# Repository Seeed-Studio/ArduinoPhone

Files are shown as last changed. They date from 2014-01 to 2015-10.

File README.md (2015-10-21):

Arduino Phone
---------------------------------------------------------

Arduino Phone

Combining Arduino and other shield modules, we make a mobile phone named Arduino Phone. Meanwhile, we printed a shell for it with the 3D printer. Although it’s not such fine as you think, even a little bit clunky, it’s still very cool. That is the point this is a cell phone made by ourselves.

<br>
### Usage:

This is a Sketchbook of Arduino.([How to use Sketchbook](http://www.seeedstudio.com/wiki/How_To_Use_Sketchbook "How to use Sketchbook"))

This Sketchbook includes a Phone demo and some libraries that included. 

We had an instructable about how to make an Arduino Phone, for more information, please refer to [Arduino Phone Instructable](http://www.instructables.com/id/ArduinoPhone/)

### TFT Shield version

The default TFT version is TFT Touch Shield V2, if you want to work with TFT v1, there's few to be modify in the code.

1. Line 34, 35 of Demo.ino
2. Line 38, 39 of UI_ArduinoPhone.cpp
3. Line 32 of UI_ArduinoPhone_dfs.h

<br>
----

This software is written by loovee ([luweicong@seeedstudio.com](luweicong@seeedstudio.com)) for seeed studio<br>
and is licensed under [The MIT License](http://opensource.org/licenses/mit-license.php). Check License.txt for more information.<br>

Contributing to this software is warmly welcomed. You can do this basically by<br>
[forking](https://help.github.com/articles/fork-a-repo), committing modifications and then [pulling requests](https://help.github.com/articles/using-pull-requests) (follow the links above<br>
for operating guide). Adding change log and your contact into file header is encouraged.<br>
Thanks for your contribution.

Seeed Studio is an open hardware facilitation company based in Shenzhen, China. <br>
Benefiting from local manufacture power and convenient global logistic system, <br>
we integrate resources to serve new era of innovation. Seeed also works with <br>
global distributors and partners to push open hardware movement.<br>

Analytics (https://github.com/igrigorik/ga-beacon)

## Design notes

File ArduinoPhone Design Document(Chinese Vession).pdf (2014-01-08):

### 1. 简介

ArduinoPhone 是一个简易的无线电话装置，可以简单的实现打电话、接电话、收发信息和 时间显示的功能。

通信部分使用 GPRS Shield 来实现，显示部分用的是 TFT Touch Shield, 写了一个较为复杂 的 firmware，实现 UI 的管理，有点击和划屏的功能。

难点在于：

1. UI 的管理
2. 键盘的字母输入
3. 划屏的效果
4. 串口数据处理

### 2. 硬件

### 2.1 使用模块

- Arduino/Seeeduino
- GPRS Shield
- TFT Touch Shield
- Grove – RTC
- 自制 7.4V 锂电池充电板，电路图另附，也可以使用 9V 电池供电

### 2.2 硬件连接

GPRS Shield 使用硬串口通信，TFT Touch Shield 使用 1.0 版本的（非 SPI 接口），简单的修 改代码可以兼容 2.0 版本的 TFT Touch Shield. Grove – RTC 使用 I

2C 接口。

连接如图 2-1 所示。

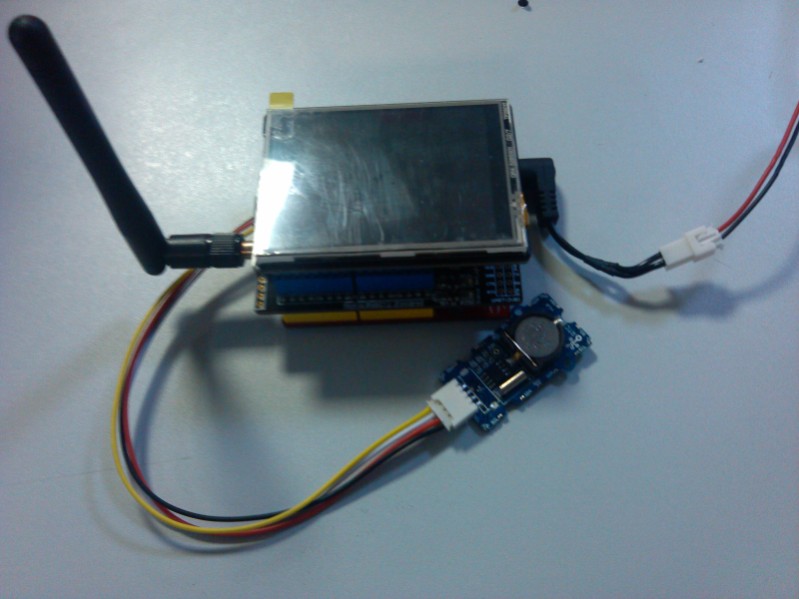
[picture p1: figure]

图 2-1 硬件连接图

### 3. 软件

### 3.1 软件流程

主架构是一个状态机，进行各个状态之间的切换，有如下 7 个状态：

- ST_TIME：时间模式，这个模式下会实时的显示当前的时间，通过 TFT 上的两个按 键可以切换到 ST_CALL 以及 ST_SMS，如果收到信息，则切换到 ST_GETMSG，如 果有电话打入，切换到 ST_GETCALL。
- ST_CALL：打电话模式，此时输入号码及拨号。按拨打键切换到 ST_CALLING。向 右拖拽 TFT 切换到 ST_TIME，向左拖拽切换到 ST_SMS
- ST_CALLING：通话模式，如果通话结束，返回 ST_CALL
- ST_GETCALL：电话打入状态，可以使用 TFT 上的 Accept 接通电话或者 Hand up 挂 断来电。通话结束后返回上一个状态。
- ST_SMS：发信息模式，可以输入收件人号码以及信息内容，俺发送键后切换到 ST_SENDSMS。向右拖拽 TFT 切换到 ST_CALL，向左拖拽切换到 ST_GETMSG。
- ST_SENDSMS：信息发送状态，信息发送完毕后返回 ST_SMS
- ST_GETMSG：读取信息状态，按下 TFT 上的 Return 可以返回上一个状态。

### 3.2 串口数据处理

GPRS Shield 是通过串口跟 Arduino 通信的，而且通信的过程是随即的，所以开了定时器 1 每隔 10ms 检测串口是否有数据，如果有数据，把串口的数据存到一个全局数组 serialDta 中， 并且把全局变量 serialGot 置位。在以上说的每一个状态中，会循环的判断 serialGot 是否有效， 如果有效，则读取 serialDta 中的数据，并且判断数据的含义。譬如串口接收到了“RING”这 个字符串，表明有来电打入，这是切换状态，切换到通话模式。

### 3.3 按键字母输入

就像我们平时用的诺基亚那样，当连续按某个按键的时候，会打印不同的字母，譬如 1 号 建，按一下的时候是 a，两下是 b，三下是 c。为了实现这个功能，需要一些时间的判断，按下 之后，如果在一定的时间之内有同一个按键按下，则当作连续按键处理。

获取时间间隔有很多种方式可以实现，我试用的是 millis()这个函数，该返回系统运行的时 间，单位是 ms。时间间隔经过测试，发现 600ms 的时候效果比较好。

### 3.4 划屏效果

首先需要获取大量点击及滑动屏幕的数据。然后分析数据得出一些规律。

当有触摸行为的时候，把数据经过简单的判断，丢到一个队列里面，进行一些判断，即可 判断出当前的触摸行为是点击或者是划屏。

这里写的有些过于简单，需要细读源代码才能发现其中的原理，难点是参数的调试。

### 3.5 使用说明：

软件流程里面已经大概说明了使用的说明，其实这个一个普通的手机类似，不需要太多的 说明，并且功能也比较单一。

## 4. 有待改进

总体来说，这个 firmware 完成了一个简单的功能，需要改进的地方很多：

- 界面的设计可以更为美观一些，因为现在使用的 TFT Touch Shield 1.0 没有 SD 卡，而 Arduino 内部的资源比较紧张，所以这部分开展起来非常困难，如果使用 TFT 2.0，会 轻松很多
- 接收信息方面，还是那个问题，资源有限，所以没能把信息存起来！
- 通信录，这个功能可以加，需要 SD 卡等掉电存储设备
- 时间设置，这个由于时间紧迫，没有做
- 闹铃，同样，时间紧迫！
- 其他~

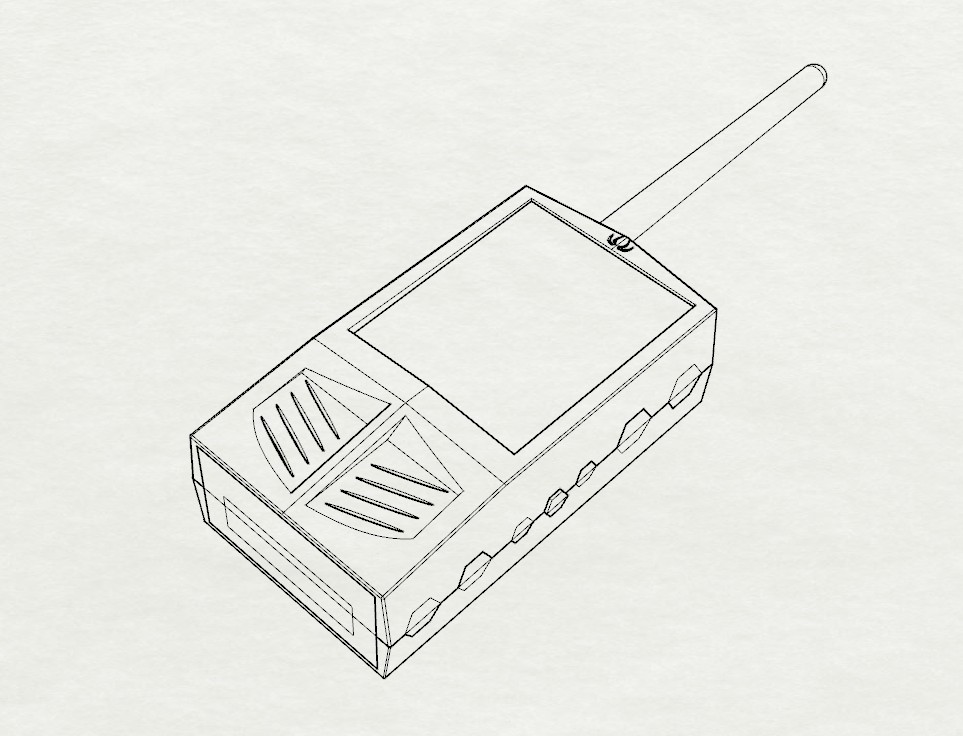
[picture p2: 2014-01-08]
3DShell/preview.jpg

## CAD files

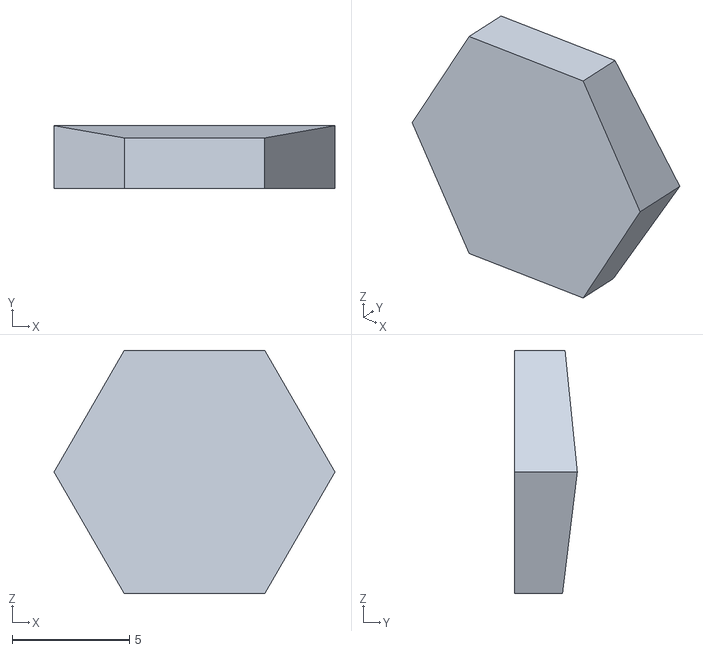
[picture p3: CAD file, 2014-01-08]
3DShell/Part_5.stl
12.0 x 2.68 x 10.4

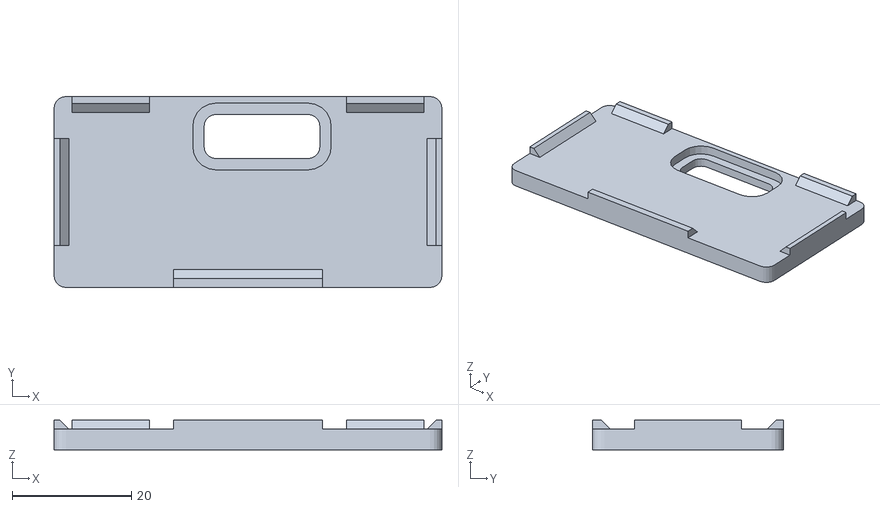
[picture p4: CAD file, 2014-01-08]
3DShell/back_Board.stl
65.0 x 32.0 x 5.00

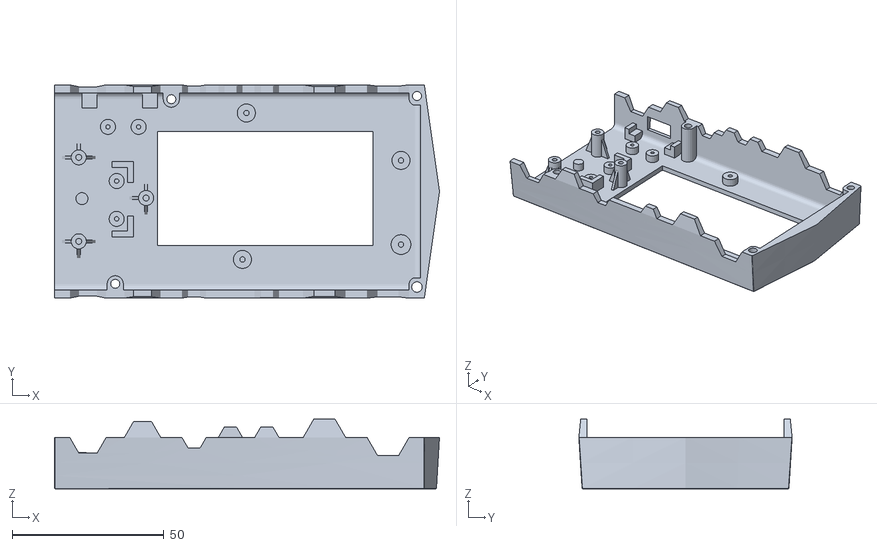
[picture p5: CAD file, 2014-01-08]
3DShell/Part_1.stl
127.0 x 70.4 x 23.1

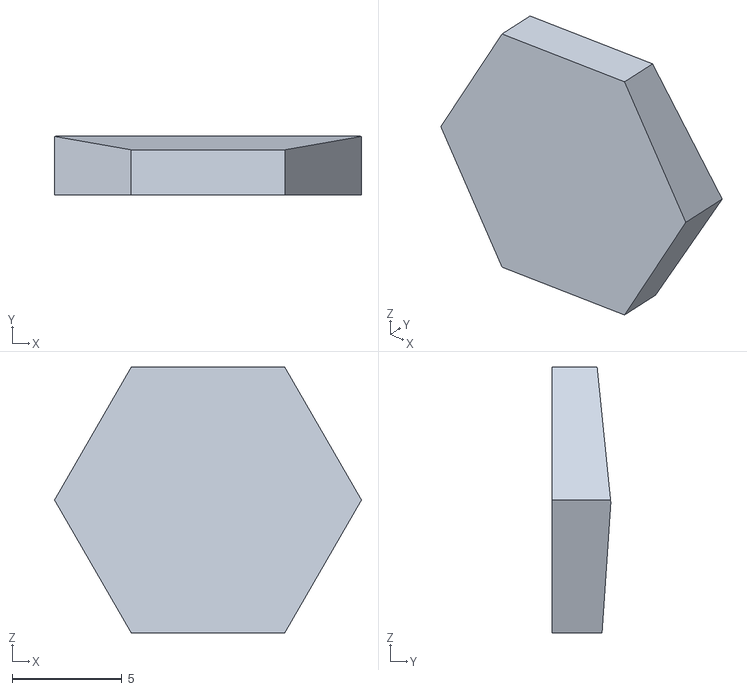
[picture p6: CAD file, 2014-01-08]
3DShell/Part_3.stl
14.0 x 2.68 x 12.1

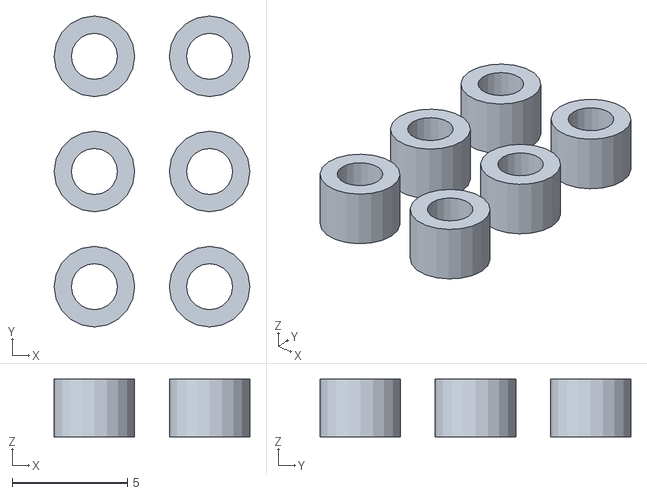
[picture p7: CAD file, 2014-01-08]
3DShell/zhuzi.stl
8.50 x 13.5 x 2.50

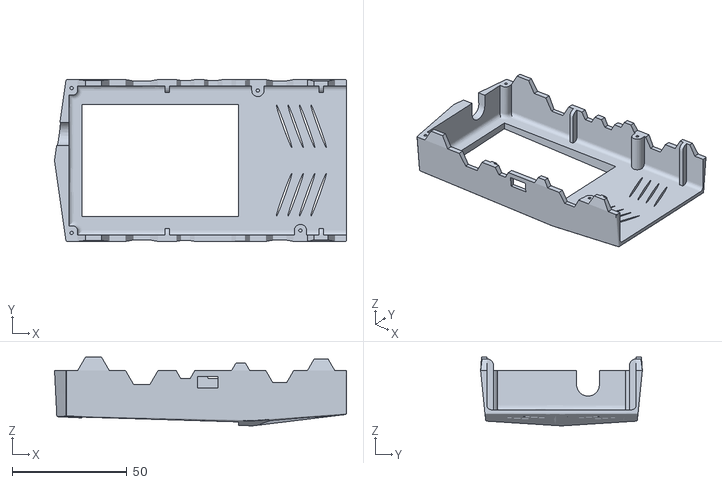
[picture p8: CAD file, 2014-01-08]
3DShell/Part_2.stl
127.0 x 70.4 x 29.9

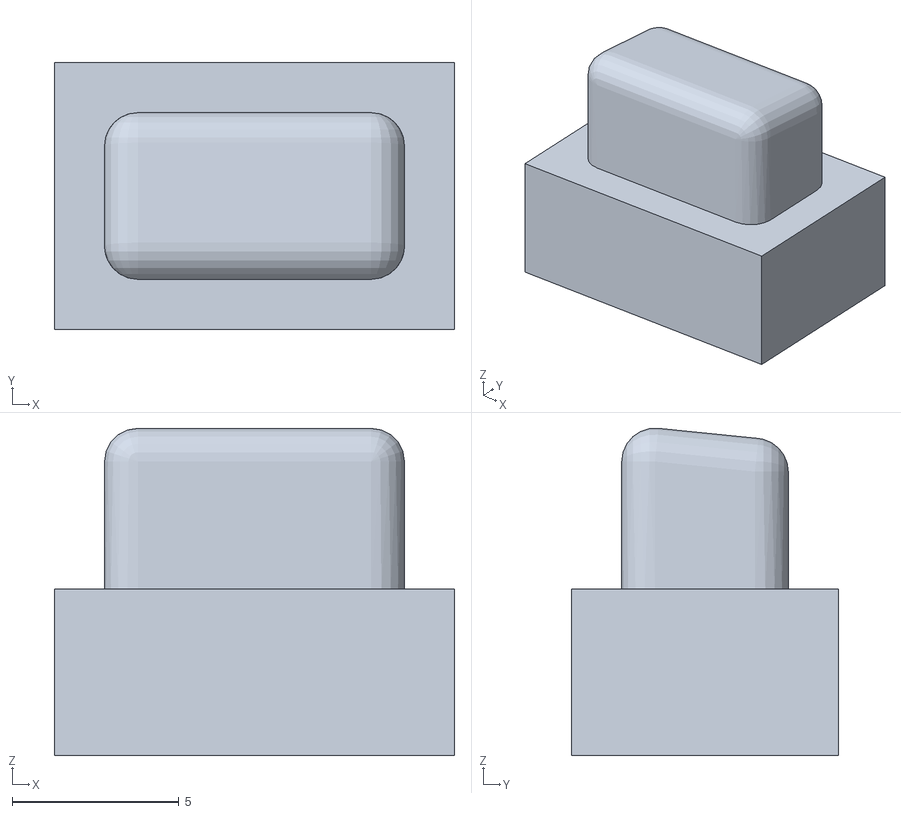
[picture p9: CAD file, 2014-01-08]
3DShell/key.stl
12.0 x 8.00 x 9.82

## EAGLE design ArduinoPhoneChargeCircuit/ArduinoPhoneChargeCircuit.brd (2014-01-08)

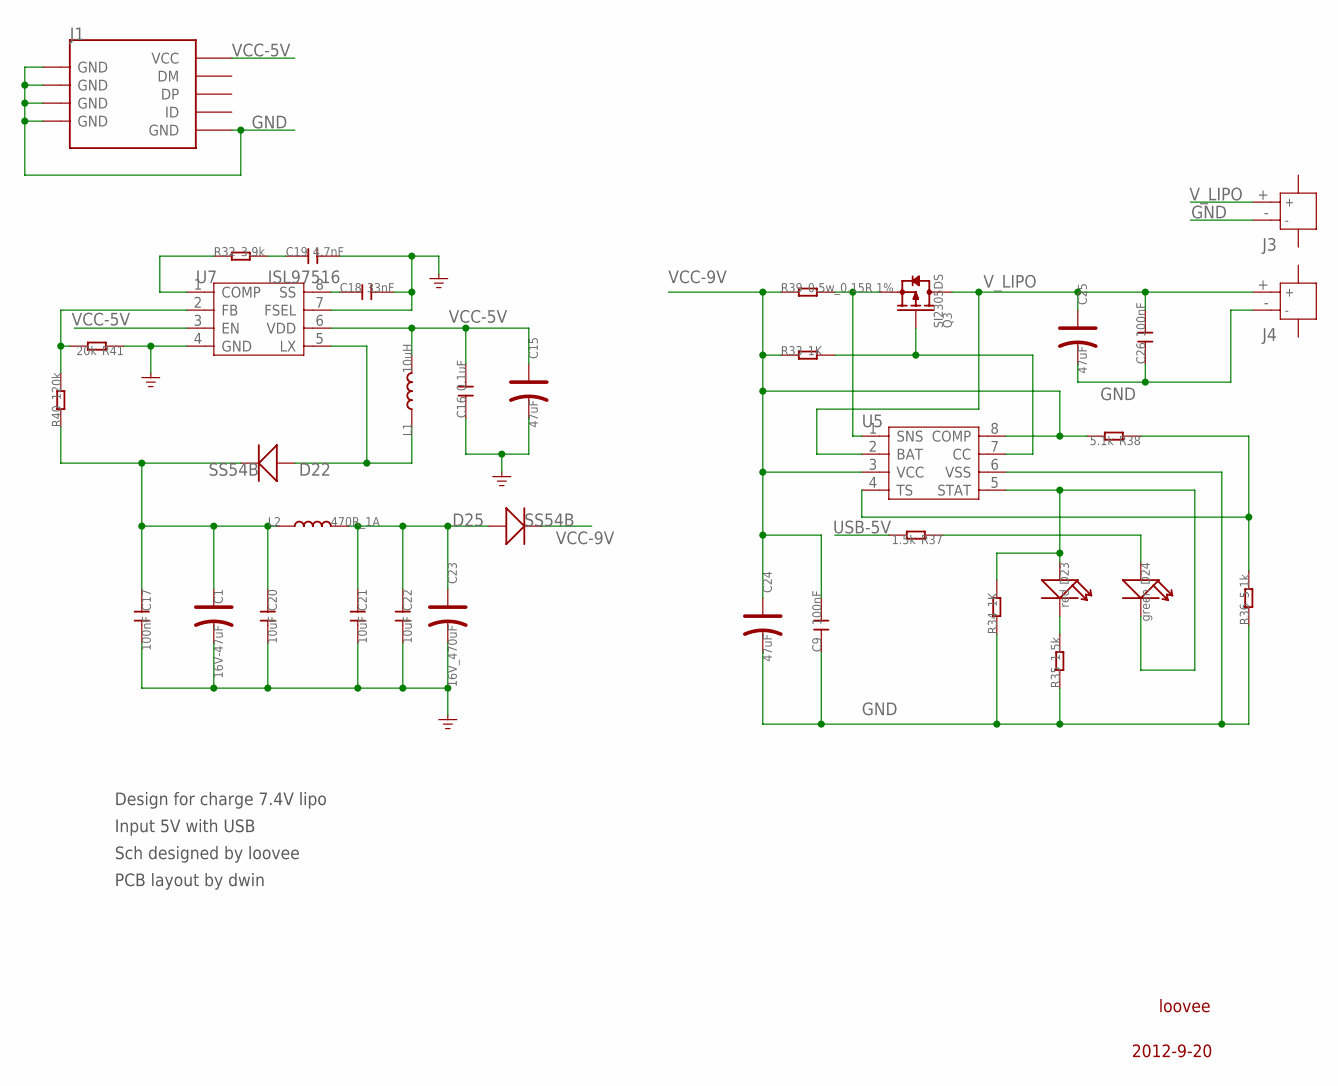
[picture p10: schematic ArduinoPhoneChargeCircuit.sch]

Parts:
C1: 16V-47uF; AVX-C
C9, C26: 100nF; 0805
C15: 47uF; 1210
C16: 0.1uF; 0603
C17: 100nF; 0603
C18: 33nF; 0603
C19: 4.7nF; 0603
C20, C21, C22: 10uF; 0805
C23: 16V_470uF; AVX-E
C24: 47uF; AVX-C
C25: 47uF; AVX-A
D22, D25: SS54B; SMB
D23: red; LED-2P-2.54-3MM
D24: green; LED-2P-2.54-3MM
J1: USB-MINIUSB-5P-STRONG; MINI-SMD-5P
J3, J4: JACK-JST-2P-SMD-PW'2.0'; JST-SMD-2.0-90D
L1: 10uH; 2626
L2: 470R_1A; L0805
Q3: SI2305DS; SOT23
R32: 3.9k; R0603
R33, R34: 1K; R0805
R35, R37: 1.5k; R0805
R36, R38: 5.1k; R0805
R39: 0.5w_0.15R 1%; R2512
R40: 120k; R0603
R41: 20k; R0603
U5: BQ2057WPW; TSSOP8
U7: ISL97516; MSOP8

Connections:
GND: C1.-, C9.1, C15.-, C16.1, C17.2, C18.2, C19.2, C20.2, C21.2, C22.2, C23.-, C24.-, C25.-, C26.1, J1.5 (GND), J1.GND@1 (GND), J1.GND@2 (GND), J1.GND@3 (GND), J1.GND@4 (GND), J3.- (2), J4.- (2), R34.1, R35.1, R36.1, R41.1, U5.6 (VSS), U7.4 (GND), U7.7 (FSEL)
unnamed: Q3.2 (S), R39.2, U5.1 (SNS)
unnamed: Q3.1 (G), R33.2, U5.7 (CC)
unnamed: D23.K (-), R35.2
unnamed: R36.2, R38.1, U5.4 (TS)
unnamed: D23.A (+), D24.K (-), R34.2, U5.5 (STAT)
unnamed: D24.A (+), R37.1
unnamed: C18.1, U7.8 (SS)
unnamed: R40.2, R41.2, U7.2 (FB)
unnamed: D22.+, L1.1, U7.5 (LX)
unnamed: R32.1, U7.1 (COMP)
unnamed: C19.1, R32.2
OUTPUT: C1.+, C17.1, C20.1, D22.-, L2.1, R40.1
OUTPUT2: C21.1, C22.1, C23.+, D25.+, L2.2
USB-5V: R37.2
VCC-5V: C15.+, C16.2, J1.1 (VCC), L1.2, U7.3 (EN), U7.6 (VDD)
VCC-9V: C9.2, C24.+, D25.-, R33.1, R38.2, R39.1, U5.3 (VCC), U5.8 (COMP)
V_LIPO: C25.+, C26.2, J3.+ (1), J4.+ (1), Q3.3 (D), U5.2 (BAT)

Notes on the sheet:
Design for charge 7.4V lipo
Input 5V with USB
Sch designed by loovee
PCB layout by dwin
loovee
2012-9-20

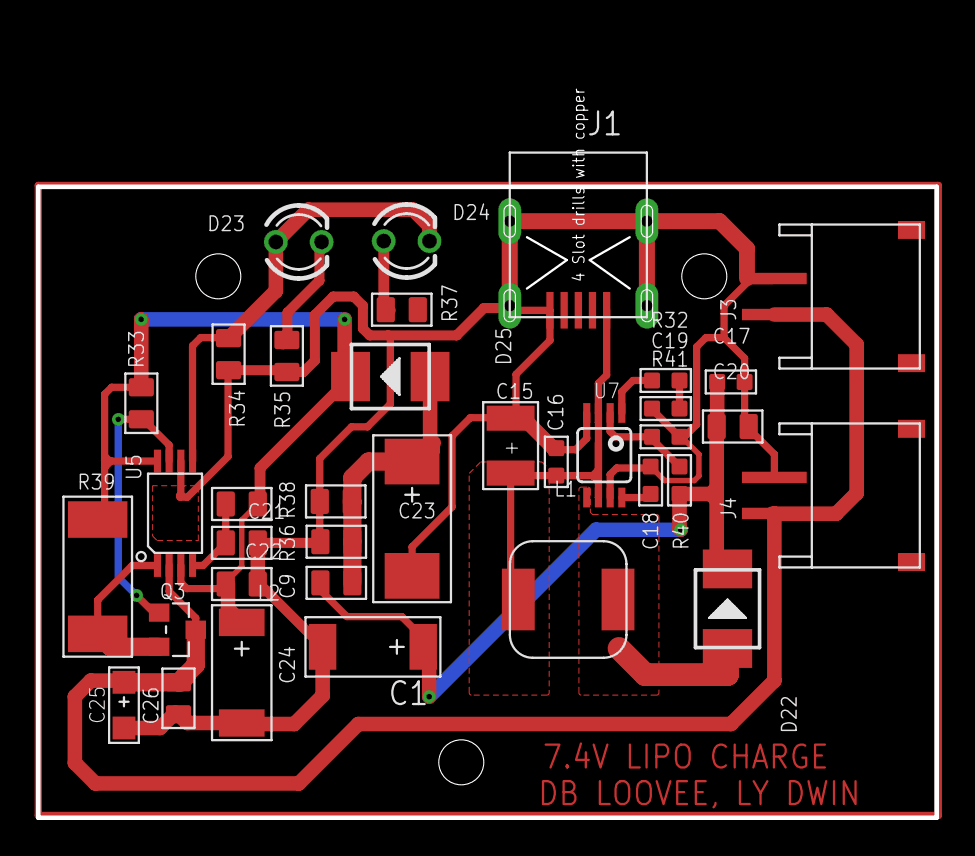
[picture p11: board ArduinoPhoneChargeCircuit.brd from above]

Board: 2 copper layers, 49.9 x 35.1 mm, 36 parts (0 on the bottom side), 17 nets.

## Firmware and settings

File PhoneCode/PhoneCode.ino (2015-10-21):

/*
  Demo.ino

  Author:Loovee

  2013-9-10
  
  The MIT License (MIT)
  
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
  THE SOFTWARE IS PROVIDED "AS IS", WITHOUT WARRANTY OF ANY KIND, EXPRESS OR
  IMPLIED, INCLUDING BUT NOT LIMITED TO THE WARRANTIES OF MERCHANTABILITY,
  FITNESS FOR A PARTICULAR PURPOSE AND NONINFRINGEMENT. IN NO EVENT SHALL THE
  AUTHORS OR COPYRIGHT HOLDERS BE LIABLE FOR ANY CLAIM, DAMAGES OR OTHER
  LIABILITY, WHETHER IN AN ACTION OF CONTRACT, TORT OR OTHERWISE, ARISING FROM,
  OUT OF OR IN CONNECTION WITH THE SOFTWARE OR THE USE OR OTHER DEALINGS IN
  THE SOFTWARE.
*/
#include <SeeedTouchScreen.h>
#include <SoftwareSerial.h>
#include <SPI.h>
#include <TimerOne.h>
#include <Wire.h>

//#include <TFT.h>          // use TFT v1
#include <TFTv2.h>          // use TFT v2

#include "phone.h"
#include "UI_ArduinoPhone_dfs.h"
#include "UI_ArduinoPhone.h"

// serial data
char serialDta[100];
unsigned char serialDtaCnt = 0;     // when use data, it shoule be changed to zero(0)
bool serialGot  = false;            // when use data, it shoule be changed to false

// serial event
void __serialEvent()
{
    disableTimer();         // disable timer irq
    while (Serial.available()) {
        char inChar = (char)Serial.read();
        serialDta[serialDtaCnt++]= inChar;
        if (inChar == '\n') {
            serialGot = true;
            serialDta[serialDtaCnt] = '\0';
            break;
        }
    }
    enableTimer();          // enable timer irq
}


int strdo(char *str)
{
    int sum = 0;
    //str_get(str);
    while(*(str)<'A' || *(str)>'Z')str++;

    if(*(str+12)>'0' && *(str+12)<'9')// >10
    {
        sum = (*(str+11)-'0')*10 + (*(str+12)-'0');
    }
    else
    sum = (*(str+11)-'0');

    return sum;
}

//const unsigned char __numAbc[10][6] PROGMEM =
char __numAbc[10][5] =
{
    {' ', '0', ' ', ' ', ' '},
    {',', '.', '!', '1', ' '},
    {'a', 'b', 'c', '2', ' '},
    {'d', 'e', 'f', '3', ' '},
    {'g', 'h', 'i', '4', ' '},
    {'j', 'k', 'l', '5', ' '},
    {'m', 'n', 'o', '6', ' '},
    {'p', 'q', 'r', 's', '7'},
    {'t', 'u', 'v', '8', ' '},
    {'w', 'x', 'y', 'z', '9'},
};

//const unsigned char __numAbcBit[10] PROGMEM =
unsigned char __numAbcBit[10] =
{
    2, 4, 4, 4, 4, 4, 4, 5, 4, 5,
};

// test if call in or msg in , return 0:  return : break;  stateNow, state
bool checkMsgCall(unsigned char stateNow)
{
    if(Phone.isMsg(serialDta))
    {
        UI.state_buf = stateNow;
        UI.state     = ST_GETSMS;

        serialGot    = false;
        serialDtaCnt = 0;
        UI.msgReadCodeMax = strdo(serialDta);
        return true;
    }

    if(Phone.isCall(serialDta))
    {
        serialGot    = false;
        serialDtaCnt = 0;
        UI.state_buf = stateNow;
        UI.state     = ST_GETCALL;
        return true;
    }

    serialGot    = false;
    serialDtaCnt = 0;
    return 0;
}
//state machine

long time1 = 0;
void stateMachine()
{
    switch(UI.state)
    {
        //***************************************main page*************************
        case ST_TIME:

        Tft.fillScreen();
        UI.getTime();
        UI.drawTimeDate(25, 90);
        UI.showMainPage();
        time1 = millis();
        while(1)
        {
            // get call
            long time = millis();
            if(time - time1 > 1000)
            {
                time1 = time;
                UI.getTime();
                if(UI.minute != UI.minute_buf)
                {
                    UI.drawTimeDate(25, 90);
                }
            }
            if(serialGot)
            {
                disableTimer();
                if(checkMsgCall(ST_TIME)){ enableTimer();break;}
                enableTimer();
            }

            if(UI.isTouch())// get touch
            {

                if(UI.getTouchRect(12, 200, 112, 270))   // phone
                {
                    UI.state        = ST_CALL;
                    UI.state_buf    = ST_TIME;
                    break;
                }
                else if(UI.getTouchRect(128, 200, 228, 270))  // sms
                {
                    UI.state        = ST_MSG;
                    UI.state_buf    = ST_TIME;
                    break;
                }
            }
        }

        break;

        //***************************************phone*****************************
        case ST_CALL:

        if(UI.state_buf == ST_MSG)
        {
            UI.drawDialogBox();
            UI.showCall();
        }
        else
        {
            Tft.fillScreen();
            UI.drawDialogBox();
            UI.showPageKB();
            UI.showCall();
        }

        while(1)
        {
            if(UI.isTouch())
            {
                while(1)
                {
                    stateCall();

                    if(serialGot)
                    {
                        if(checkMsgCall(ST_CALL))break;
                    }
                    if(UI.state != ST_CALL)break;
                }
            }
            if(serialGot){
                disableTimer();
                if(checkMsgCall(ST_CALL)){enableTimer();break;}
                enableTimer();
            }
            // check if call in or msg

            if(UI.state != ST_CALL)break;
        }

        UI.callCount = 0;

        break;

        //***************************************make phone calling***************
        case ST_CALLING:
        Tft.fillScreen();
        Tft.drawString("calling...", 20, 100, 3, WHITE);
        Tft.fillRectangle(10, 200, 230, 50, GRAY1);
        Tft.drawString("HANDUP", 20, 215, 3, RED);
        while(1)
        {
            if(UI.getTouchRect(10, 200, 240, 250))// hand up
            {
                Phone.handUpCall();
                UI.state     = UI.state_buf;
                UI.state_buf = ST_CALLING;
                break;
            }

            // serial get data
            if(serialGot)
            {
                disableTimer();
#if I2CUART
                UI.I2C_Uart(serialDta);
#endif
                if(Phone.isCallOver(serialDta))
                {
                    UI.state     = UI.state_buf;
                    UI.state_buf = ST_CALLING;
                    enableTimer();
                    break;
                }
                serialGot    = false;
                serialDtaCnt = 0;
                enableTimer();
                delay(1);
            }

        }

        Tft.drawString("calling...", 20, 100, 3, BLACK);
        Tft.fillRectangle(10, 200, 230, 50, BLACK);
        Tft.drawString("HANDUP", 20, 215, 3, BLACK);

        break;
        //***************************************get call*************************
        case ST_GETCALL:

        Tft.fillScreen();
        Tft.drawString("calling...", 20, 100, 2, WHITE);
        Tft.fillRectangle(10, 200, 100, 50, GRAY1);
        Tft.fillRectangle(130, 200, 100, 50, GRAY1);
        Tft.drawString("ACCEPT", 15, 215, 2, GREEN);
        Tft.drawString("HANDUP", 135, 215, 2, RED);
        while(1)
        {
            // serial get data
            if(serialGot)
            {
                disableTimer();
                if(Phone.isCallOver(serialDta))
                {
                    UI.state     = UI.state_buf;
                    UI.state_buf = ST_GETCALL;
                    enableTimer();
                    break;
                }
                serialGot    = false;
                serialDtaCnt = 0;
                enableTimer();
            }

            if(UI.getTouchRect(10, 200, 110, 250))// accept
            {
                Phone.acceptCall();
                Tft.drawString("calling...", 20, 100, 2, BLACK);
                Tft.drawString("call connected!", 20, 100, 2, WHITE);
                Tft.drawString("call connected!", 20, 100, 2, BLACK);
            }

            // hand up
            if(UI.getTouchRect(130, 200, 230, 250)) // hand up
            {
                UI.state     = UI.state_buf;
                UI.state_buf = ST_GETCALL;
                Phone.handUpCall();
                break;
            }

        }

        Tft.fillRectangle(10, 200, 100, 50, BLACK);
        Tft.fillRectangle(130, 200, 100, 50, BLACK);

        break;
        //***************************************message***************************
        case ST_MSG:


        if(UI.state_buf == ST_CALL)
        {
            UI.drawMsgDialogBox();
            UI.showMsg();
        }
        else
        {
            Tft.fillScreen();
            UI.showPageKB();
            UI.drawMsgDialogBox();
            UI.showMsg();
        }

        while(1)
        {
            if(UI.isTouch())
            {
                while(1)
                {
                    stateMsg();
                    if(UI.state != ST_MSG)break;
                    if(serialGot)
                    {
                        disableTimer();
                        if(checkMsgCall(ST_MSG)){enableTimer();break;}
                        enableTimer();
                    }
                }
            }
            if(serialGot)
            {
                disableTimer();
                if(checkMsgCall(ST_MSG)){enableTimer();break;}
                enableTimer();
            }
            if(UI.state != ST_MSG)break;
        }

        UI.msgCount     = 0;
        UI.msgNumCount  = 0;


        break;

        //***************************************message sending*******************
        case ST_SENDSMS:

        Tft.fillScreen();
        Tft.drawString("SMS Sending", 20, 120, 3, WHITE);
        while(1)
        {
            // delay(1000);
            if(Phone.isMsgSendOver())
            {
                UI.state_buf = ST_SENDSMS;
                UI.state     = ST_MSG;
                break;
            }
        }
        Tft.drawString("SMS Sending", 20, 120, 3, BLACK);

        break;
        //**************************************get msg******************************
        case ST_GETSMS:

        UI.drawReadMsgPage();
        // get new msg

        Serial.print("AT+CMGR=");Serial.println(UI.msgReadCodeMax, DEC);
        UI.msgReadCodeNow = UI.msgReadCodeMax;

        while(1)
        {
            stateMsgRead();
            if(UI.state != ST_GETSMS)
            break;
        }

        break;

        default:
        ;
    }
}

// state: phone call


void stateCall()
{
    unsigned char button = 0;
    long timercall = millis();
    UI.getTouch(&button);
    long t = millis();
    if(button>0 && button<10)
    {

        UI.callAdd(button);
    }
    else if(button == 11)
    {
        long deltT = t - timercall;

        if((UI.callCount < 1) && (deltT>400))
        {
            UI.callAdd(15);
        }
        else UI.callAdd(0);
    }
    else if(button == 12)
    {
        UI.callDel();
    }
    else if(button == 10)// call
    {
        Phone.makeCall();
        UI.callCount = 0;
        UI.state_buf = ST_CALL;
        UI.state     = ST_CALLING;
    }
    else if(button == TOUCH_DRAG_LEFT)
    {
        UI.state_buf = ST_CALL;
        UI.state     = ST_MSG;
    }
    else if(button == TOUCH_DRAG_RIGHT)
    {
        UI.state_buf = ST_CALL;
        UI.state     = ST_TIME;
    }
}

// state: message
void stateMsg()
{
    long time =  millis();
    long time1 = time;
    unsigned char buttonNum     = 100;
    unsigned char buttonNumBuf  = 100;

    int count = 0;
    unsigned char button = 0;

    char let2[4] = {'a', 'b', 'c', '4'};

    if(!UI.isTouch())return;

    unsigned char msgState = 1;
            
    while(1)
    {
        long time1 = millis();
        msgState = UI.getMsgInputState();

        if(msgState == 1)
        {
            UI.state_msg = MSG_STATE_NUM;
            delay(100);
            button = 0;
        }
        else if(msgState == 2)
        {
            UI.state_msg = MSG_STATE_TXT;
            delay(100);
            button = 0;
        }
        else
        {
            button = UI.getTouch(&button);
        }
        
        // input txt
        
        if(button == TOUCH_DRAG_LEFT)
        {
            UI.state_buf = ST_MSG;
            UI.state     = ST_GETSMS;
            break;
        }
        else if(button == TOUCH_DRAG_RIGHT)
        {
            UI.state_buf = ST_MSG;
            UI.state     = ST_CALL;
            break;
        }
        else if(button>0 && button<10)
        {
            if(UI.state_msg == MSG_STATE_TXT)
            {
                buttonNum    = button;
                UI.msgAdd(__numAbc[buttonNum][count % __numAbcBit[buttonNum]], RED);
                count++;
                time = time1;
            }
            else
            {
                buttonNum = button;
                UI.msgNumAdd(buttonNum);
                buttonNum = 100;
            }
        }
        else if(button == 11)//0
        {
            if(UI.state_msg == MSG_STATE_TXT)
            {
                buttonNum = 10;
                UI.msgAdd(__numAbc[0][count % __numAbcBit[0]], RED);
                count++;
                time = time1;
            }
            else
            {
                long t = millis();
                long deltT = t - time1;

                if(deltT > 500 && UI.msgNumCount == 0)
                UI.msgNumAdd(15);
                else
                UI.msgNumAdd(0);
                buttonNum = 100;
            }
        }
        else if(button == 12) // del
        {
            if(UI.state_msg == MSG_STATE_TXT)
            UI.msgDel();
            else
            UI.msgNumDel();
            break;
        }
        else if(button == 10)       // send
        {
            Phone.msgSend();
            UI.state_buf  =  ST_MSG;
            UI.state      =  ST_SENDSMS;
            break;
        }

        if(((time1 - time) > 600)&& UI.state_msg == MSG_STATE_TXT)
        {
            if(buttonNum>0 && buttonNum<10)UI.msgAdd(__numAbc[buttonNum][(count-1) % __numAbcBit[buttonNum]]);
            else if(buttonNum == 10)UI.msgAdd(__numAbc[0][(count-1) % 2]);
            break;
        }
    }
}

// state read msg
void stateMsgRead()
{
    unsigned char button  = 0;
    unsigned char button1 = 0;
    unsigned char cnt = 0;
    unsigned flag_getMsgTime = 0;
    char s[20];
    while(1)
    {
        if(serialGot)
        {
            disableTimer();
#if I2CUART
            UI.I2C_Uart(serialDta);
            delay(5);
#endif
            if(flag_getMsgTime == 1)// get msg
            {
#if I2CUART
                int sss = UI.getReadMsgMsg(serialDta);
#else
                UI.getReadMsgMsg(serialDta);
#endif

#if I2CUART
                sprintf(s, "txt long = %d\r\n", sss);
                UI.I2C_Uart(s);
                delay(5);
                UI.I2C_Uart("\r\ntxt:\t");
                delay(5);
                UI.I2C_Uart(UI.msgReadTxt);
                delay(5);
                UI.I2C_Uart("\r\n");
#endif

                UI.drawReadMsg();
                flag_getMsgTime = 0;
            }
            else if(UI.getReadMsgTimeAndFrom(serialDta, UI.msgReadNum, UI.msgReadTime))
            {
#if I2CUART
                UI.I2C_Uart("num:\t");
                delay(5);
                UI.I2C_Uart(UI.msgReadNum);
                delay(5);
                UI.I2C_Uart("\r\ndate:\t");
                delay(5);
                UI.I2C_Uart(UI.msgReadTime);
                UI.I2C_Uart("\r\n");
#endif
                flag_getMsgTime = 1;
            }

            serialGot = false;
            serialDtaCnt = 0;
            enableTimer();
        }

        if(UI.isTouch())
        {
            if(UI.getTouchRect(0, 270, 239, 319))
            {
                //UI.state     = UI.state_buf;
                UI.state     = UI.state_buf;
                UI.state_buf = ST_GETSMS;
                button1 = 0;
                break;
            }
            else button1 = UI.getTouch(&button);
        }
        else button1 = 0;
        //drag right: read format
        if(button1 == TOUCH_DRAG_RIGHT)
        {
            button1 = 0;
            cnt = 0;
            if(UI.msgReadCodeNow>2)
            UI.msgReadCodeNow--;
            Serial.print("AT+CMGR=");Serial.println(UI.msgReadCodeNow, DEC);
        }
        //drag left: read <-- msg
        else if(button1 == TOUCH_DRAG_LEFT)
        {
            cnt = 0;
            button1 = 0;
            //if(UI.msgReadCodeNow<UI.msgReadCodeMax && UI.msgReadCodeMax != 1)
            UI.msgReadCodeNow++;
            Serial.print("AT+CMGR=");Serial.println(UI.msgReadCodeNow, DEC);
        }
        // return

    }
}
// setup
void enableTimer()
{
    Timer1.attachInterrupt(__serialEvent);
}

void disableTimer()
{
    Timer1.detachInterrupt();
}

//setup
void setup()
{
    Phone.init();
    UI.init();
    Wire.begin();
    Timer1.initialize(10000);                // 10 ms
    Timer1.attachInterrupt(__serialEvent);   // attach the service routine here
}

// loop
void loop()
{
    stateMachine();
}

/*********************************************************************************************************
  END FILE
*********************************************************************************************************/

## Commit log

2013-04-17 change ArduinoPhoneCode.ino to ArduinoPhone.ino
2013-07-17 ArduinoPhoneChargeCircuit added
    [ArduinoPhoneChargeCircuit.brd, ArduinoPhoneChargeCircuit.sch]
2013-07-22 3D Shell stl file
    [Part_1.stl, Part_2.stl, Part_3.stl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]
